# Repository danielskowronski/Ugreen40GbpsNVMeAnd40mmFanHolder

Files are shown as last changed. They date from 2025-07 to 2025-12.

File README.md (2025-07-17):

# UGREEN 40Gbps M.2 NVMe Enclosure and 40mm Fan Holder - 3D Parametric Model

3D Parametric Model (OpenSCAD) of holder for [UGREEN 40Gbps M.2 NVMe Enclosure](https://web.archive.org/web/20250118234648/https://www.ugreen.com/products/ugreen-40gbps-m-2-nvme-enclosure-with-cooling-fan) and standard 40mm PC fan. 

3D model files and print photos hosted on [printables.com/model/1358090-ugreen-40gbps-m2-nvme-enclosure-and-40mm-fan-holde](https://www.printables.com/model/1358090-ugreen-40gbps-m2-nvme-enclosure-and-40mm-fan-holde).

## Objective

Main objective is keeping drive in natural position (largest plane parallel to surface) with proper airflow and adding backup/support 40mm fan next to exhaust of built-in one. The holder is designed to be either placed on top of desk/bench/shelf or attached underneath desk/bench/shelf. Additionally, it's designed to be stackable vertically (screwable) and placed horizontally (no interferences on surfaces).

3D model is designed in such a way that print should use as little material as possible, which will not limit access to ambient air. Another goal is to have print as simple and quick as possible, for example by eliminating supports.

## Project status tracker

- [x] objective, limitations and general idea described
- [x] design and layout of parts described, BOM prepared
- [x] all fixed parts measured, initial dimensions of parametric parts planned
- [x] structure of SCAD code, base variables set, primitive initial version of top/bottom and virtual vertical plates
- [x] sync of SCAD dimensions variables and design docs, including full explanation for each of them, replace `to be determined` in this doc
- [x] working version of top/bottom plate - code, test print, dimensions fitting
- [x] working version of disk plate - code, test print, dimensions fitting
- [x] working version of fan plate - code, test print, dimensions fitting
- [x] docs updated with images explaining complex text descriptions of 3D objects (based on prototype renders)
- [x] assembly of all parts, testing connections and fit to external objects
- [x] modify disk plates to enable any form of airflow along enclosure
- [x] explain how images are rendered
- [x] explain how code is structured, remove scad/README.md
- [x] final object code improvements
- [x] final print, finalization of print settings and materials
- [x] photos and model publication on Printables.com
- [ ] further improvements

## Repository structure

1. Documentation:
   1. [Design](./docs/DESIGN.md) - introduction to general "architecture" and description of parts, known limitations
   2. [BOM](./docs/BOM.md) - printable and non-printable parts with their dimensions (Bill Of Materials)
   3. [Important notes on material (filament)](./docs/MATERIAL.md)
   4. [Printing and assembly](./docs/ASSEMBLY.md)
   4. [SCAD code](./docs/SCAD.md)
2. [`scad`](./scad/) directory with OpenSCAD source code that uses [BOSL2](https://github.com/BelfrySCAD/BOSL2) library (see [SCAD.md](./docs/SCAD.md))
3. [Printables.com model](https://www.printables.com/model/1358090-ugreen-40gbps-m2-nvme-enclosure-and-40mm-fan-holde) with parts rendered into STL, printer settings and photos of assembled holder.

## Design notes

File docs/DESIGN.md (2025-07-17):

# Design

## Intro

Holder is split into 6 parts, but there are only 3 different sub-objects and each appears twice:

1. top/bottom plate (XY plane)  
2. fan holder plate (YZ plane)
3. disk holder plate (YZ plane)

Each part type will be described as it lies flat on the print bed. This means that top/bottom plate stays laying on XY plane as when assembled, but fan and disk plates are rotated - assembled YZ plane becomes XY plane when printed and described.

Vertical plates (disk/fan) are connected to horizontal ones (top/bottom) using M3 screws (8-10mm) and nuts - `HoriToVertScrew`.

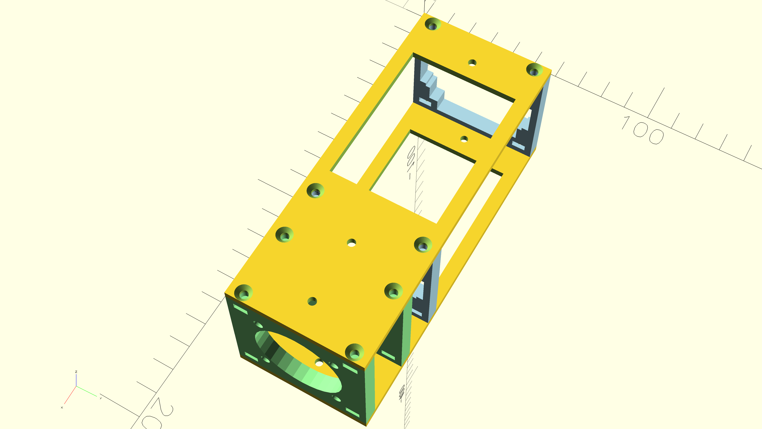
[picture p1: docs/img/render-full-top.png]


When looking from XZ side of the assembled holder, there are the following objects parallel to the Z axis:

1. first fan plate *(light green)*
2. fan itself
3. second fan plate *(light green)*
4. free space between fan and disk - 5mm (`FanToDiskMargin`)
5. YZ front side of disk (with air outlet) starts
6. first part of disk before first disk plate (`DiskHangingMargin`)
7. first disk plate; distance between 2nd fan plate and 1st disk plate is sum of 4th, 5th and 6th elements here *(light blue)*
8. central part of the disk between 1st and 2nd disk plate (approx 67mm, but this is auto-calculated as `DiskHangingMiddle`)
9. second disk plate *(light blue)*
10. final part of the disk, ending with YZ back side of enclosure with air inlet and Thunderbolt connector - 5mm (`DiskHangingMargin`)

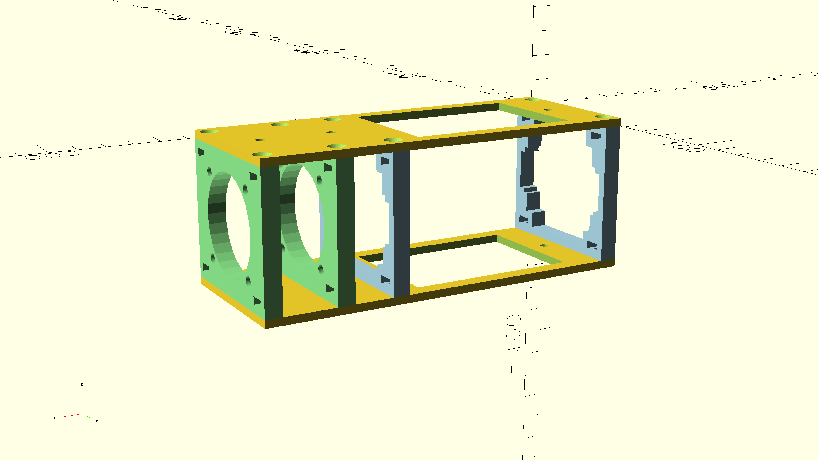
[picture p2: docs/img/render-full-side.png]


The above elements sum up to `HPD`, which is the longer dimension of the top plate.

Disk plates are not aligned with edges of the enclosure to provide safe tolerations and ensure the disk does not fall off them. 

This means that in current design, part of the disk hangs outside the holder. Rejected alternatives are:

1. extending length of top/bottom plates only, but this provides no benefits, and it's unclear if extension should cover enclosure body with or without Thunderbolt cable
2. extending length of top/bottom plates and adding extra disk plate on very end of holder, but this does not solve issue with cable and adds plastic that doesn't improve holder strength

Strain relief for cable is purposefully left outside the scope of this project, as cables shipped with enclosure are too short and other ones vary too much.

## Architecture

### Top/bottom plates

Top/bottom plates are flat cuboids with flat screw holes for perpendicularly attaching fan+disk plates and non-flat screw holes for vertical stacking. Both types are M3. Flat-head screws are used for smooth external sides, while fall-back to non-flat head is dictated by the fact this connection is made internally in stack and need to simplify model (that way top and bottom plates are identical; otherwise one plate would require conical indentation for screw head and other plate would have no extra cone as it is place for washer + nut).

Additionally, top/bottom plates are hollowed out in a way that keeps the plate rigid and keeps space for pieces of self-adhesive Velcro to allow mounting of the whole holder to a flat surface (widely available tape from TESA is 20mm wide, which also matches the depth of fan).

Height / thickness is 3mm (`HoriPlateThick`), which is arbitrary. Width is determined by width of vertical plates (`HPW=VPW`; effectively the largest hole + margins) and sum of dimensions from vertical plates and distances (`HPD`).

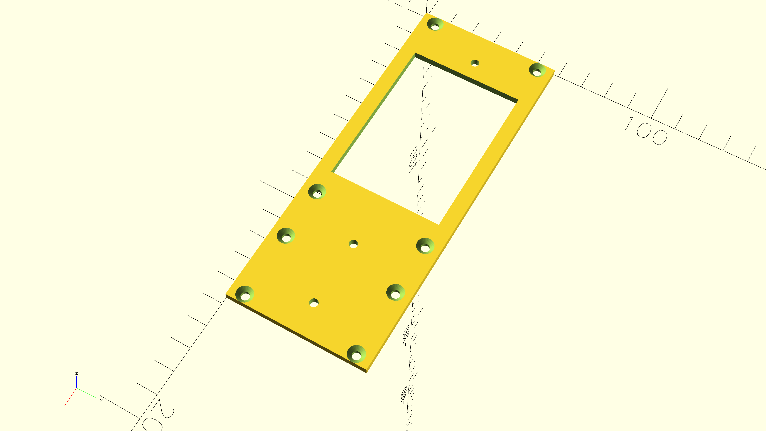
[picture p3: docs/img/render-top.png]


### Virtual vertical plates

Fan and disk holder plates are based of the same "virtual vertical plate" model (*virtual* as in C++ virtual function). Here the base model will be described, it'll not be rendered for printing, but fan and disk plates will use it as base for adding their holes. It is also a flat cuboid, but only has 4 sets of holes. Each hole set is placed around the corner of the plate and consists of:

1. rectangular hole from top to bottom
   - place for nut matching flat-head screw holes in top/bottom plate
   - nut aligned for screw parallel to X axis
   - approximately 6mm (`ConnNutHoleWidth`) in Y and 3mm (`ConnNutHoleDepth`) in X
2. cylindrical hole laying on side (bottom of cylinder is on YZ)
   - place for screw matching flat-head screw holes in top/bottom plate
   - placed in a way that centre of cylinder base is centre of YZ plane of the other hole
   - diameter determined by M3 thread, with some extra margins needed because no supports can be inserted for this overhang (`HoriToVertScrew`)

Height / thickness is 6.75mm (`VertPlateThick`) to accommodate nut (`ConnNutHoleWidth`) and M3 screw hole with safe margins. Size is determined by size of largest hole in appropriate dimension (width/depth) + margins: `VPW` and `VPD`.

At least 3mm (`VertPlateMargin`) are required as margin not to be hollowed to keep structure safe. This value is arbitrary.

### Fan plates

Fan plate has the following cutouts:

1. circular hole for airflow placed in the centre of plate, diameter around 38mm
2. 4 mounting holes for M4 screws, placed on edges of virtual 32x32mm square

Adding extra cutouts adds extra work and doesn't improve airflow.

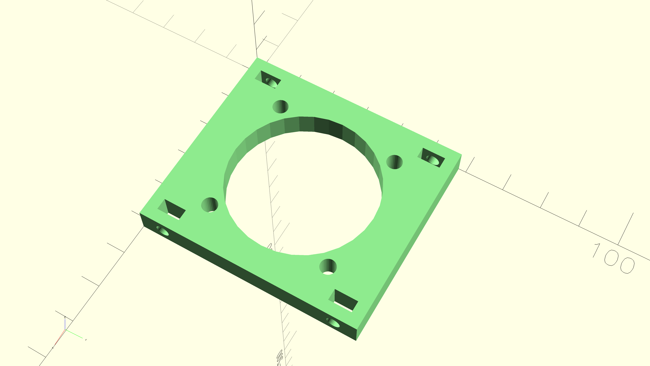
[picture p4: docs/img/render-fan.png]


### Disk plates

The disk plate has the following cutouts:

1. main hole for YZ side of NVMe enclosure
   - base size is 46.1x19.1mm, but we need extra 0.1mm (half of `DiskPadding`) from each side to push enclosure without too much friction (to counteract that, Kapton tape can be used)
   - it's centred
2. 4 extra rectangular holes stacked on top of each other to effectively fully hollow out plate keeping edges needed to keep disk in place and not to interfere with screw holes (this could have been one circle and mounting brackets for disk)
   - extra holes are used here to enhance airflow and limit contact position of disk plate and hot enclosure.
   - they are set up in such a way that each corner of enclosure touching disk plates has a contact length of 2mm (`DiskFrameEdge`) on each side

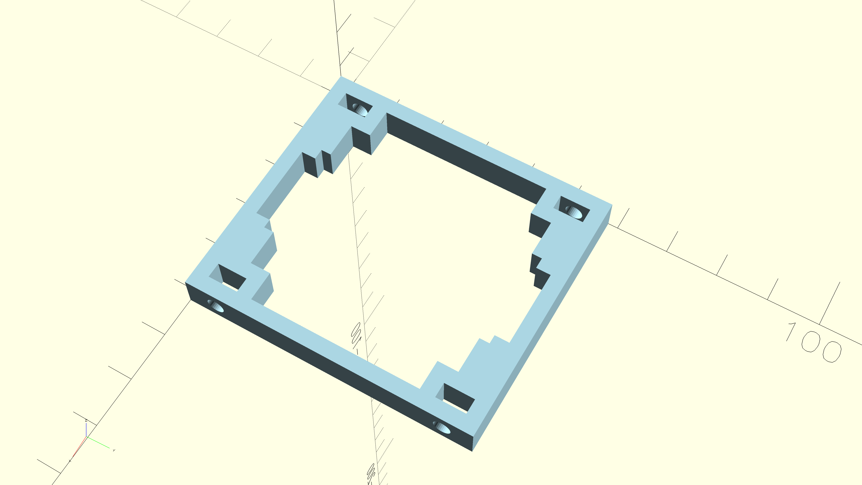
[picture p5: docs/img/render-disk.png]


## Known limitations

1. Airflow is very simplistic; holder was designed to add extra fan as support for built-in one and slightly pull hot air radiating from bottom surface (the one that acts as heat sink for NVMe disk); since this enclosure seems to keep temperatures within my disk ranges (although on higher end) and I don't have knowledge in fluid mechanics I'm not implementing any extra parts yet
2. As mentioned in intro to design, strain relief for Thunderbolt cable is outside of scope of this project; for non-stacked holder placed on top of a surface there shouldn't be any problems even with thick cables, but when stacking or using upside-down some self-adhesive cable guides should be used
3. There's no explicit path for fan cable, but one can use cutouts in disk plates to keep the fan connector around the disk connector
4. In current form, only fixed speed fans make sense, as there's no holder for thermal probe and fan controller in 3D object; moreover, it makes more sense to have one multichannel controller for stackable disk array than to duplicate it and incorporate in every holder
5. Fan power is outside the scope of this project, USB to 3pin / 4pin PWM fan power supplies are widely available (mind the voltage as some fans are 5V and some are 12V, but their connectors are the same)
6. This holder only ensures extra space is kept between enclosure and any adjacent objects (like desk surfaces) and adds fan for stronger airflow; it does not enhance actual heat dissipation - this could be achieved by attaching extra radiators on top and bottom surfaces of enclosure (e.g. using double-sided thermal tape), but it could require tweaking positions of disk plates

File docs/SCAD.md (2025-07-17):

# SCAD code

## Files

### [`common.scad`](./scad/common.scad)

- global dimension variables (all referenced to docs)

### [`horizontal.scad`](./scad/horizontal.scad) 

-> [DESIGN.md - Top/Bottom Plates](./DESIGN.md#topbottom-plates)

- `HP_Base` - module which is a simple cuboid with desired size
- `HVP_Screw` - define screw hole for flat-head M3 connecting vertical and horizontal plates
- `HP_ScrewPair` - define screw pair for each vertical plate, used to simplify translations
- `HP_Full` - base cuboid with subtracted horizontal/vertical screws and extra stacking screws
- `HP_Hollowed`
  - `HP_Full` with extra hole for extra airflow and saving material
  - this is the module to be rendered into 3D print

### [`vertical.scad`](./scad/vertical.scad)

-> [DESIGN.md - Virtual Vertical Plates](./DESIGN.md#virtual-vertical-plates)

- `VP_Base` - module which is a simple cuboid with desired size
- `VP_ConnHoles` - define positive horizontal/vertical connection holes (nut hole and cylinder for screw thread)
- `VP_Half` - full plate with only top connection holes subtracted
- `VP_Full` 
  - magic intersection of two `VP_Half` mirrored, hack not to rotate and translate `VP_ConnHoles`
  - this is the module used in `disk.scad` and `fan.scad`

### [`fan.scad`](./scad/fan.scad) 

-> [DESIGN.md - Fan Plates](./DESIGN.md#fan-plates)

- `FanScrewHole` - module generating screw holes for attaching fan, M4
- `FP_Base`
  - `VP_Base` with screw holes for fan and main airflow hole removed
  - this is the module to be rendered into 3D print

### [`disk.scad`](./scad/disk.scad) 

-> [DESIGN.md - Disk Plates](./DESIGN.md#disk-plates)

- `DP_Airflow_Side` - module for airflow holes from left/right side of disk enclosure 
- `DP_Base`
  - `VP_Base`with main disk hole and all extra airflow holes (including 2x `DP_Airflow_Side`) removed
  - this is the module to be rendered into 3D print

### [`render.scad`](./scad/render.scad) 

- code to render images for this documentation (ViewPort settings included) and STL files
- simple comment/uncomment is needed to select which object to render

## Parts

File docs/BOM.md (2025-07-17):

# Printable and non-printable parts with their dimensions (Bill Of Materials)

## Fan

Standard 40x40x20mm PC fan ([example specification](https://noctua.at/en/products/fan/nf-a4x20-flx)). Size in code is `FanWidth`x`FanHeight`x`FanDepthBase` Extra grill is not required, inlet is protected by object layout.

Mounting holes are for M4 (`FanScrewDia`) screws and their centres are spaced by 32mm (`FanScrewDist`). 

Depth is 20mm (`FanDepthBase`) by specification, but an extra 0.65mm (`FanDepthExtra`) is required to accommodate anti-vibration material.

Diameter of fan airflow (blades) is 38mm (`FanHoleDia`).

## Enclosure

UGREEN 40Gbps M.2 NVMe Enclosure has no official dimensions. Here it'll be used without rubber bumpers to enhance airflow.

Without tolerances, it's 46.1mm wide (`DiskWidth`), 19.1mm tall (`DiskHeight`) and 118.2mm deep (`DiskDepth`). 

Air outlet vent is 28.5mm wide and 4mm tall, centred vertically and placed around 1.5mm from the bottom. Air inlet and Thunderbolt connectors are placed similarly on the other side. This is irrelevant to the current version of holder.

## Printable parts

6 individual parts in total (should be printable on one plate):

1. 2x render of `xy.scad` = top and the bottom plates
2. 2x render of `fan.scad` = 2x fan plate
3. 2x render of `disk.scad` = 2x disk plate 

See [MATERIAL.md](./MATERIAL.md) for important note related to material used.

## Non-printable parts

For mounting fan to two fan plates:

1. 4x M4x38 or M4x40 screw, non-flat head (flat head is nicer but requires changing one of fan plates)
2. 4x M4 nut

For connecting all the four plates (2x fan and 2x disk plates) to top and bottom plates:

1. 16x M3x8 or M3x10 screw with flat head
2. 16x M3 nut

Optionally, for vertical stacking (between each instance):

1. 3x M3x12mm screw with non-flat head
2. 3x M3 nut
3. 6x M3 washer

Options for placing on flat surfaces:

- self-adhesive Velcro, for example 20mm (`TapeWidth`) wide tape from TESA, requires 2 strip pairs 57mm in length (`VPW`)
- self-adhesive strips, for example 2x medium 3M Command should fit
- 4x self-adhesive rubber feet

Optionally:

- Kapton tape to wrap around enclosure on contact point to make it sit tightly

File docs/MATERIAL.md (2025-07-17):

# Important notes on material (filament)

## Filament type

It's very important to note that parts of disk plate will be touching the aluminium body of the enclosure and taking up the heat. 

While in theory neither UGREEN 40Gbps enclosure (especially with extra fan) or any other enclosure should externally to values around glass transition temperature of PLA (55-60°C), **it is critical to take this thermal properties of material used for disk plates into account**. 

One should measure temperature of enclosure without extra fan when stress-testing the disk for long period of time (e.g. 30 minutes) and compare it with specification of filament used, most notably **glass transition temperature**.

ABS is always safest (with enclosure externally at 100-110°C any drive would be long dead), PETG seems fine as well (it reaches glass transition at 80-85°C). Some extra idea is to use thermal insulation for parts of enclosure that touch disk plate, but then dimensions should be tweaked.

## My decision to use PLA-CF

I decided to use PLA with Carbon Fiber for all parts, including disk plates. Refer to [BOM - Filament type](./BOM.md#filament-type) before choosing material. 

My specific setup includes:

- WD RED SN700 connected over TB4, which in this enclosure provides 32/8 Gbps (R/W)
- 2 layers of Kapton tape 
- constant monitoring of internal disk temperature using S.M.A.R.T.
- regular manual checks using thermal-imaging camera
- both fans - Noctua NF-A4x20 FLX 5000 RPM 

Results from holder version `v0.2.0`:

- ambient: 25°C
- during stress-testing for 10 minutes:
  - internal disk probe: 60°C
  - exterior: 46°C
- normal use (backups):
  - internal disk probe: 46°C
  - exterior: 42°C
- idle:
  - internal disk probe: 43°C
  - exterior: 38°C

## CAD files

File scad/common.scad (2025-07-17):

include <BOSL2/std.scad>
include <BOSL2/screws.scad>
$fn=32;

// Objective Dimensions - Fan
FanWidth=40;         // Width of the fan; docs -> BOM.md#fan
FanHeight=40;        // Height of the fan; docs -> BOM.md#fan
FanScrewDist=32;     // Distance between fan screws; docs -> BOM.md#fan
FanScrewDia=4.0;     // Diameter of fan screws; docs -> BOM.md#fan
FanDepthBase=20;     // Thickness of fan - base; docs -> BOM.md#fan
FanDepthExtra=0.65;  // Extra thickness of antivibration material; docs -> BOM.md#fan
FanHoleDia=38;        // Hole for airflow; docs -> BOM.md#fan

// Objective Dimensions - Disk enclosure (withour rubber bumper)
DiskWidth=46.1;      // Width of the disk enclosure; docs -> BOM.md#enclosure
DiskHeight=19.1;     // Height of the disk enclosure; docs -> BOM.md#enclosure
DiskDepth=118.2;     // Depth/length of the disk enclosure; docs -> BOM.md#enclosure

// Objective Dimensions - Other
TapeWidth=20;        // Width of adhesive tape to keep safe margins; docs -> BOM.md#non-printable-parts

// Parametric Dimensions
DiskPadding=0.2;         // Extra margins for the disk enclosure to fit in the holder; docs -> DESIGN.md#disk-plates
VertPlateMargin=3.0;     // Minimum amount of solid material between holes and edges of fan/disk (vertical) plate; docs -> DESIGN.md#virtual-vertical-plates
HoriPlateThick=3.0;      // Thickness of the top/bottom (horizontal) plate; docs -> DESIGN.md#topbottom-plates
VertPlateThick=6.75;     // Thickness of the fan/disk (vertical) plate; docs -> DESIGN.md#virtual-vertical-plates
FanToDiskMargin=5;       // Extra space between fan and disk enclosure; docs -> DESIGN.md#intro
DiskHangingMargin=10;    // Distance fron ensosure edge to disk plate edge (to ensure disk does not fall off the plate); docs -> DESIGN.md#intro
HoriToVertScrew="M3,10"; // Screw connecting horizontal and vertical plates; docs -> DESIGN.md#intro and DESIGN.md#virtual-vertical-plates
DiskFrameEdge=2;         // how long should be supports for disk (v0.1.0 would be DiskWidth+DiskPadding) ;docs -> DESIGN.md#disk-plates
ConnNutHoleWidth=6;      // vertical plate nut hole width; docs -> DESIGN.md#virtual-vertical-plates
ConnNutHoleDepth=3;      // vertical plate nut hole depth; docs -> DESIGN.md#virtual-vertical-plates

// Core structural dimensions - autocalculated, described in context of assembled holder
ConnThreadHoleLenght=VertPlateMargin;                                           // This controls nut hole, it shouldn't break minimum distance between edges of the plate and holes; just alias
HoriToVertScrewDistanceToEdge=VertPlateMargin+3;                                // Distnace from edge of horizontal plate to center of screw; just alias
DiskHangingMiddle=DiskDepth-2*(DiskHangingMargin+VertPlateThick);               // Length of disk between both disk plates; docs -> DESIGN.md#intro
VPW=max(DiskWidth, FanWidth)  +2*HoriToVertScrewDistanceToEdge;                 // Width of the vertical plate; docs -> DESIGN.md#virtual-vertical-plates
VPD=max(DiskHeight, FanHeight)+2*HoriToVertScrewDistanceToEdge;                 // Height of the vertical plate; docs -> DESIGN.md#virtual-vertical-plates
VPH=VertPlateThick;                                                             // Height of the vertical plate; docs -> DESIGN.md#virtual-vertical-plates
HPW=VPW;                                                                        // Width of the horizontal plate; docs -> DESIGN.md#topbottom-plates
HPH=HoriPlateThick;                                                             // Height of the horizontal plate; docs -> DESIGN.md#topbottom-plates
HPD=                                                                            // Depth of the horizontal plate; docs -> DESIGN.md#topbottom-plates
  VPH+                     // 1st fan plate
  FanDepthBase+            // Fan depth
  FanDepthExtra+           // Extra antivibration material
  VPH+                     // 2nd fan plate
  FanToDiskMargin+         // Extra space between fan and disk enclosure
  DiskHangingMargin+       // Distance from enclosure edge to disk plate edge
  VPH+                     // 1st disk plate
  DiskHangingMiddle+       // Length of disk between both disk plates
  VPH+                     // 2nd disk plate
  0;                       // No extra space at the end

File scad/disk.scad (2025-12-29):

include <vertical.scad>

module DP_Airflow_Side(){
  cuboid([DiskHeight+DiskPadding-DiskFrameEdge*2,DiskFrameEdge*2, VPH*2], anchor=LEFT+FRONT);
}

MarginToHolesX=ConnThreadHoleLenght+ConnNutHoleDepth+ConnThreadHoleLenght; // similar to VertPlateMargin but including HoriToVertScrew
MarginToDiskY=(VPW-DiskWidth-DiskPadding)/2; // width between edge of plate and disk sides (left/right) 

module disk_edges(vpd=VPD){
  // main disk edges
  translate([(vpd-DiskHeight-DiskPadding)/2,MarginToDiskY,0]){
    cuboid([DiskHeight+DiskPadding,DiskWidth+DiskPadding,2*VPH], anchor=LEFT+FRONT);
  }
}
module airflow_holes_sides(){
  // holes for airflow between disk and left/right edges of frame
  translate([(VPD-DiskHeight+DiskPadding)/2+DiskFrameEdge,0,0]){
    // left 
    translate([0,VertPlateMargin,0])  DP_Airflow_Side();
    
    // right
    translate([0,VPW-VertPlateMargin-DiskFrameEdge*2,0]) DP_Airflow_Side();
  }
}
module airflow_hole_vert_widest(){
  // hole for airflow above and below disk - widest one, squezed under and abobe HoriToVertScrew 
  translate([MarginToHolesX,MarginToDiskY+DiskFrameEdge,0]) {
    cuboid([VPD-2*(MarginToHolesX),VPW-2*(MarginToDiskY+DiskFrameEdge), VPH*2], anchor=LEFT+FRONT);
  }
}
module airflow_hole_vert_tallest(){
  // hole for airflow above and below disk - highest one, between left and right HoriToVertScrew
  translate([VertPlateMargin,HoriToVertScrewDistanceToEdge*2,0]) {
    cuboid([VPD-2*VertPlateMargin,VPW-4*HoriToVertScrewDistanceToEdge, VPH*2], anchor=LEFT+FRONT);
  }
}
module disk_all_holes(){
  union(){
    disk_edges();
    
    airflow_holes_sides();
    
    airflow_hole_vert_widest();
    
    airflow_hole_vert_tallest();
  }
}


module DP_Base(){
  color("lightblue")
  difference(){
    // TODO: everything here would benefit in readability from CENTER achoring
    VP_Full();
    disk_all_holes();
  }
}

// DP_Base();

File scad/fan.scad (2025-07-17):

include <vertical.scad>

module FanScrewHole(){
  translate([VPD/2,VPW/2,0])
    cylinder(VPH*2, d=FanScrewDia, center=true);
}

module FP_Base(){
  color("lightgreen")
  difference(){
    VP_Full();
    
    translate([-FanScrewDist/2, -FanScrewDist/2, 0]) FanScrewHole(); // Fan screw - top-left
    translate([-FanScrewDist/2, +FanScrewDist/2, 0]) FanScrewHole(); // Fan screw - top-right
    translate([+FanScrewDist/2, -FanScrewDist/2, 0]) FanScrewHole(); // Fan screw - bottom-left
    translate([+FanScrewDist/2, +FanScrewDist/2, 0]) FanScrewHole(); // Fan screw - bottom-right
    
    translate([VPD/2,VPW/2,0]) cylinder(VPH*2, d=FanHoleDia, center=true); // Fan airflow
  }
}

// no space to hollow more

//FP_Base();

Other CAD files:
scad/horizontal.scad
scad/render.scad
scad/v2/common.scad
scad/v2/render.scad
scad/v2/tb.scad
scad/v2/triple.scad
scad/vertical.scad
scad/xy.scad
scad/yz.scad

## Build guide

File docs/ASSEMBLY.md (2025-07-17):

# Assembly

## Printing

My setup for printing on Creality K1C:

- *Hyper PLA-CF* -> see [MATERIAL.md](./MATERIAL.md) !!!
- 0.16mm layers
- 2 wall loops
- 10% cross-hatch in-fill
- approx 46g of filament for full holder

## Assembly instructions

### Preparation

Holes for the fan may be too tight, especially if you use 3D-printed screw (e.g. when you don't have such long screw at hand). If so, take a short metal M4 screw and screw it in, then out. A power drill may be helpful.

Useful tools:

- screwdrivers for screws
- small, flat-blade screwdriver for keeping M3 nut in place in vertical plates
- tweezers

### Steps

While top and bottom plates are identical, here one will be elected as top.

1. Select one of top/bottom plates to be the top one
2. Screw first vertical plate to top plate - it can be any of two fan and two disk plates, but it should be easiest to start with first fan plate:
   1. insert nut into first rectangular hole (on vertical plate)
   2. while keeping nut in place by finger, align edge of vertical plate that has nut inserted and screw hole of inner side of top plate - that is one on which you can't see conical indent for screw head
   3. insert flat-head M3 screw from external side of top plate and tighten it
   4. ensure that vertical plate is parallel to shorter edge of top plate
3. Screw the second screw of first plate 
4. In a same way, attach remaining three plates (two screws per plate) in correct order
5. Align bottom plate on vertical plates in a way that screw holes align and conical indents are on outside
6. Attach bottom plate to vertical plates using eight M3 screws and nuts, repeating same procedure as for top plate
7. Insert fan between fan plates from side and align screw holes; ensure that airflow direction (that should be marked on fan itself) matches airflow direction of enclosure (inlet is near Thunderbolt connector, outlet is facing fan plates)
8. Insert four M4 screws into fan plates and fan, starting from side of object
9. Place M4 washers and nuts inside (between fan and disk plate - this may require large tweezers or long nose pliers)
10. Tighten fan screws
11. Insert NVMe enclosure without rubber bumper from the back: Thunderbolt connector should not face fan, but no observable differences whether it's on top or bottom (i.e. enclosure can be positioned naturally or upside-down)
12. Position enclosure depth, so there are a few millimetres between it and fan plate
13. Attach optional adhesives to top/bottom plate that will be touching the desk/bench/shelf
14. Connect fan and ensure it blows outside - air from around enclosure should be sucked outside
15. Connect enclosure to computer, generate some load on disk, then disconnect fan and double check that enclosure fan blows in the same direction as fan; otherwise extra fan will be fighting built-in fan and may lead to overheating

Hint: fan should be active even when disk (and host computer) is not, to cool it down after use. Use external power supply or ensure that you use always-powered USB port on computer.

Alternatively, fan-related parts can be assembled first: 

1. Hold in place: fan plate - fan - fan plate 
2. Screw using M4 screws and nut
3. Attach to top and then bottom plate like you'd work with individual fan plates

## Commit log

2025-07-13 docs: objective, project status tracker, repository structure, known limitations, design and parts description, non-printable BOM, printable part list, assembly instructions
2025-07-13 scad: attempt at MVP
    [common.scad, disk.scad, fan.scad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]
2025-07-14 docs: update assembly instructions after first print, add renders as visual aids
    [test.scad]
2025-07-14 scad: disk plate: enhance airflow by adding more cutouts
    [common.scad, disk.scad]
2025-07-17 docs and scad: finalize and polish code, sync it with docs, improve docs adding section for code itself,
    [common.scad, disk.scad, fan.scad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]
2025-07-17 docs: update printables.com, fix incorrect render
2025-12-29 scad: new variant for stack of 3 enclosures and 120mm fan
    - cosmetic changes for disk plates model, needed to not repeat code
    - new `triple.scad` code for universal plate used in new variant (3 stacked enclosures and 120mm fan blowing at 120x20mm side)
    - docs, renders and model will be added later
    [disk.scad, triple.scad]
2025-12-30 scad: extend new variant for 3 enclosures by adding top/bottom plates
    - reorg repo to move new variant to `v2`
    - split code to new `common.scad`, keep `triple.scad` for disk holder, add `tb.scad` for top/bottom plate and `render.scad` for assembled view
    - new approach with `render_element` used to control whether render to STL from file or include module to make complex render
    - add fan model module to test screw alignement
    - color code parts
    [common.scad, render.scad, tb.scad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]
2025-12-30 scad: new variant - minimal offset fix, improve code
    [common.scad, render.scad, tb.scad]
